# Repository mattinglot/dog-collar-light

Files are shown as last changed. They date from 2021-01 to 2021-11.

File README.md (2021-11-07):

# Dog Collar Light
Developed by Matt Inglot

## Overview
This is the LED dog collar light PCB and firmware that I built for my dog Joey and a few of his friends.

Overview of the Light:
https://youtu.be/FvTPfEKD1Q0

Details about the PCB Design:
https://youtu.be/JEl7wfQJ-MM

## License
* The firmware source code is licensed under the MIT license.
* The PCB design is licensed under the Creative Commons Attribution Share Alike 4.0 International license.

See the LICENSE file in each folder of the project for the applicable license.

## Share Your Creations!
If you end up building one of these lights, I would really love to know! Please leave a comment on https://youtu.be/FvTPfEKD1Q0 with a link to your work.

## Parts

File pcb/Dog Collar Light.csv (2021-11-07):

Ref | Value | Part | Footprint | Description | Vendor
BT1 | 2xCR2032 | Device:Battery | mi-footprint:BatteryHolder_Keystone_3024 | Multiple-cell battery
C3 | 22uF | Device:C | Capacitor_SMD:C_0805_2012Metric_Pad1.15x1.40mm_HandSolder | Unpolarized capacitor
C4 | 22uF | Device:C | Capacitor_SMD:C_0805_2012Metric_Pad1.15x1.40mm_HandSolder | Unpolarized capacitor
C5 | 22uF | Device:C | Capacitor_SMD:C_0805_2012Metric_Pad1.15x1.40mm_HandSolder | Unpolarized capacitor
C6 | 22uF | Device:C | Capacitor_SMD:C_0805_2012Metric_Pad1.15x1.40mm_HandSolder | Unpolarized capacitor
C7 | 0.1uF | Device:C | Capacitor_SMD:C_0805_2012Metric_Pad1.15x1.40mm_HandSolder | Unpolarized capacitor
D1 | LED_RGB | Device:LED_RGB | mi-footprint:LED_Cree-SLV6A | RGB LED, 6 pin package
D2 | LED_RGB | Device:LED_RGB | mi-footprint:LED_Cree-SLV6A | RGB LED, 6 pin package
J1 | AVR-ISP-6 | Connector:AVR-ISP-6 | Connector_PinHeader_2.54mm:PinHeader_2x03_P2.54mm_Vertical | Atmel 6-pin ISP connector
Q1 | MBT3904DW1T1G | dk_Transistors-Bipolar-BJT-Arrays:MBT3904DW1T1G | digikey-footprints:SOT-363 | TRANS 2NPN 40V 0.2A SC88
R1 | 100 | Device:R | Resistor_SMD:R_0805_2012Metric_Pad1.15x1.40mm_HandSolder | Resistor
R2 | 68 | Device:R | Resistor_SMD:R_0805_2012Metric_Pad1.15x1.40mm_HandSolder | Resistor
R3 | 68 | Device:R | Resistor_SMD:R_0805_2012Metric_Pad1.15x1.40mm_HandSolder | Resistor
R4 | 100 | Device:R | Resistor_SMD:R_0805_2012Metric_Pad1.15x1.40mm_HandSolder | Resistor
R5 | 68 | Device:R | Resistor_SMD:R_0805_2012Metric_Pad1.15x1.40mm_HandSolder | Resistor
R6 | 68 | Device:R | Resistor_SMD:R_0805_2012Metric_Pad1.15x1.40mm_HandSolder | Resistor
R7 | 330 | Device:R | Resistor_SMD:R_0805_2012Metric_Pad1.15x1.40mm_HandSolder | Resistor
R8 | 10k | Device:R | Resistor_SMD:R_0805_2012Metric_Pad1.15x1.40mm_HandSolder | Resistor
R9 | 10K | Device:R | Resistor_SMD:R_0805_2012Metric_Pad1.15x1.40mm_HandSolder | Resistor
R10 | 330 | Device:R | Resistor_SMD:R_0805_2012Metric_Pad1.15x1.40mm_HandSolder | Resistor
R11 | 330 | Device:R | Resistor_SMD:R_0805_2012Metric_Pad1.15x1.40mm_HandSolder | Resistor
R12 | 6.8k | Device:R | Resistor_SMD:R_0805_2012Metric_Pad1.15x1.40mm_HandSolder | Resistor
R13 | 6.8k | Device:R | Resistor_SMD:R_0805_2012Metric_Pad1.15x1.40mm_HandSolder | Resistor
S1 | 222PJVAAR | dk_Tactile-Switches:1825910-6 | mi-footprint:Switch_222PJVAAR | SWITCH TACTILE SPST-NO 0.05A 24V
U2 | ATtiny84A-SSU | MCU_Microchip_ATtiny:ATtiny84A-SSU | Package_SO:SOIC-14_3.9x8.7mm_P1.27mm | 20MHz, 8kB Flash, 512B SRAM, 512B EEPROM, debugWIRE, SOIC-14

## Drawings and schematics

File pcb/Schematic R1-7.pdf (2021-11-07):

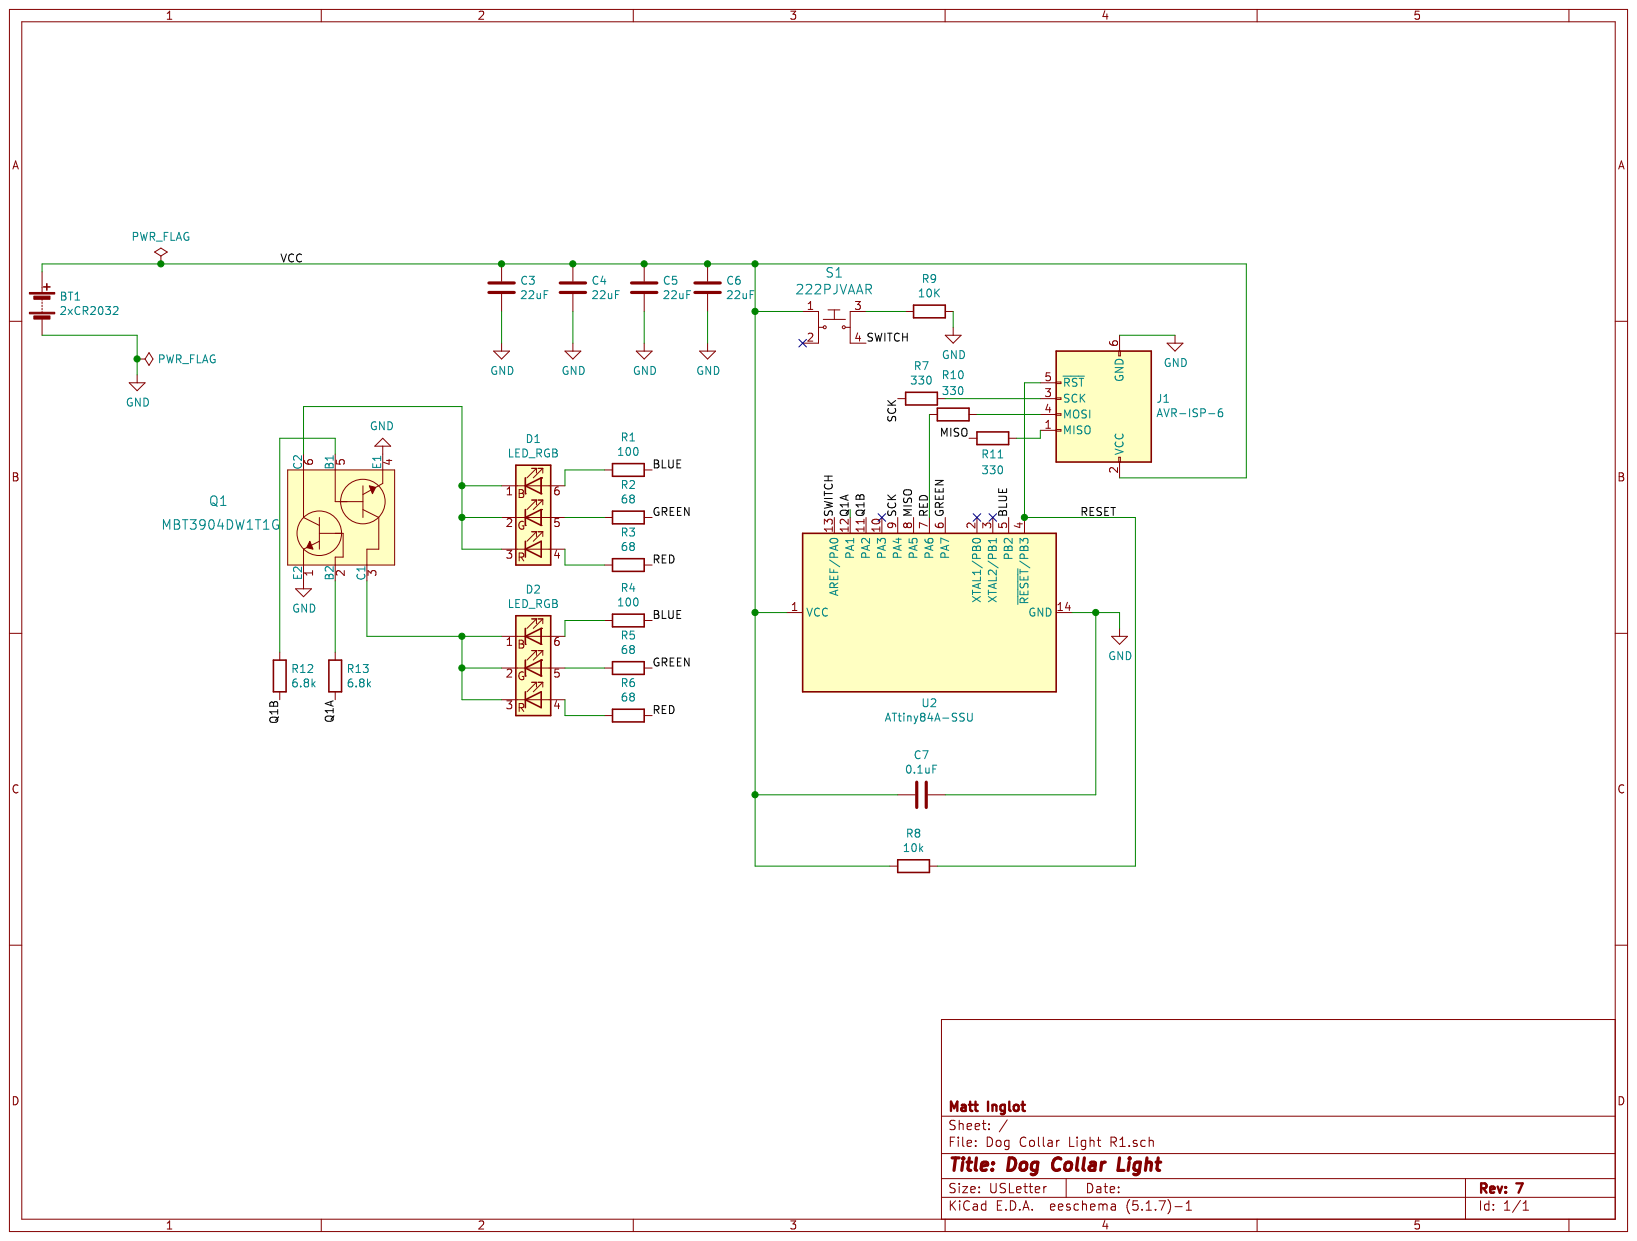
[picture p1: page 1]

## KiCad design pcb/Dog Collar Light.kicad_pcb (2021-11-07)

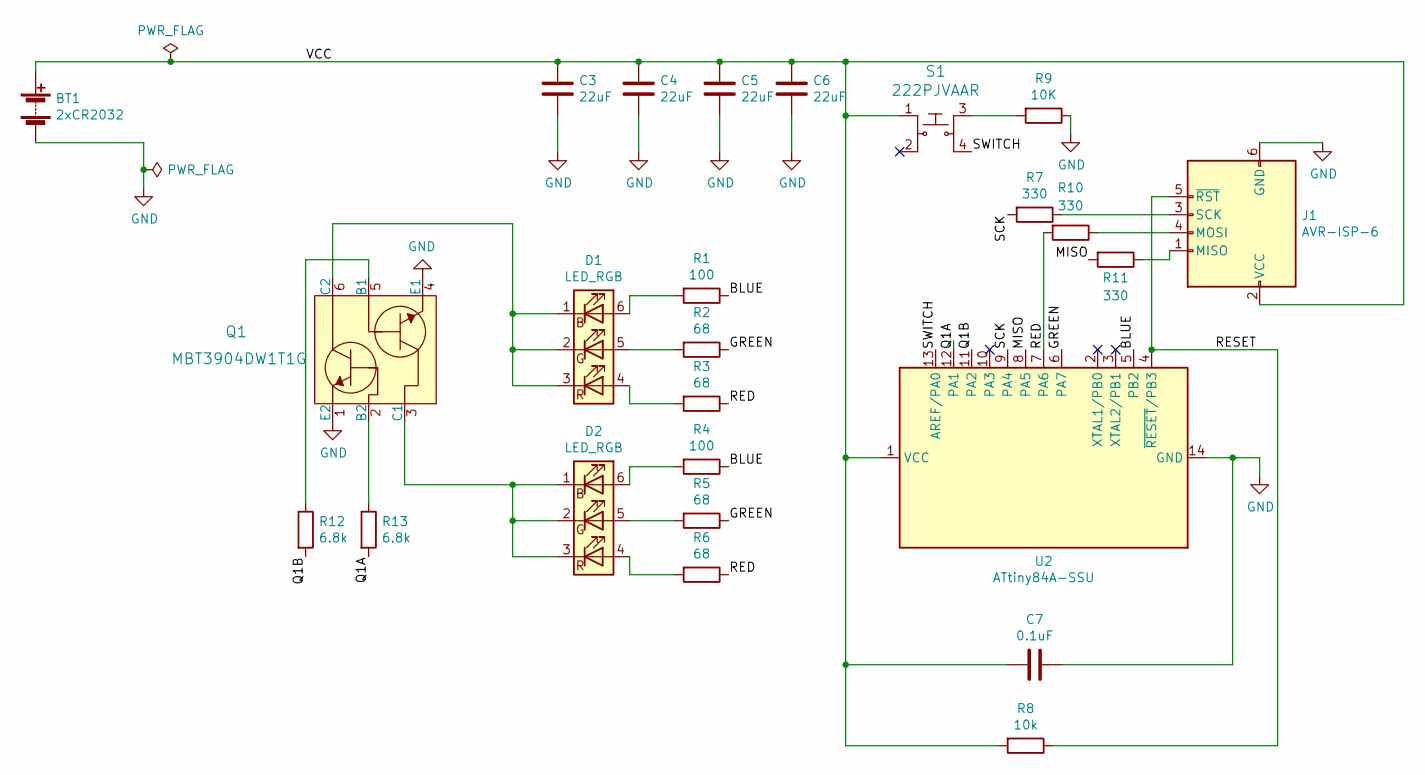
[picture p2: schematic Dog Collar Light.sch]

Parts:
BT1: 2xCR2032; BatteryHolder_Keystone_3024
C3, C4, C5, C6: 22uF; C_0805_2012Metric_Pad1.15x1.40mm_HandSolder
C7: 0.1uF; C_0805_2012Metric_Pad1.15x1.40mm_HandSolder
D1, D2: LED_RGB; LED_Cree-SLV6A
J1: AVR-ISP-6; PinHeader_2x03_P2.54mm_Vertical
Q1: MBT3904DW1T1G; SOT-363; MPN MBT3904DW1T1G; Digi-Key_PN MBT3904DW1T1GOSCT-ND
R1, R4: 100; R_0805_2012Metric_Pad1.15x1.40mm_HandSolder
R2, R3, R5, R6: 68; R_0805_2012Metric_Pad1.15x1.40mm_HandSolder
R7, R10, R11: 330; R_0805_2012Metric_Pad1.15x1.40mm_HandSolder
R8: 10k; R_0805_2012Metric_Pad1.15x1.40mm_HandSolder
R9: 10K; R_0805_2012Metric_Pad1.15x1.40mm_HandSolder
R12, R13: 6.8k; R_0805_2012Metric_Pad1.15x1.40mm_HandSolder
S1: 222PJVAAR; Switch_222PJVAAR; MPN 1825910-6; Digi-Key_PN 450-1650-ND
U2: ATtiny84A-SSU; SOIC-14_3.9x8.7mm_P1.27mm

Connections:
/BLUE: R1.1, R4.1, U2.5 (PB2)
/GREEN: R2.1, R5.1, U2.6 (PA7)
/MISO: R11.2, U2.8 (PA5)
/Q1A: R13.2, U2.12 (PA1)
/Q1B: R12.2, U2.11 (PA2)
/RED: R3.1, R6.1, R10.2, U2.7 (PA6)
/SCK: R7.2, U2.9 (PA4)
/SWITCH: S1.4, U2.13 (AREF/PA0)
/VCC: BT1.1 (+), C3.1, C4.1, C5.1, C6.1, C7.2, J1.2 (VCC), R8.2, S1.1, U2.1 (VCC)
GND: BT1.2 (-), C3.2, C4.2, C5.2, C6.2, C7.1, J1.6 (GND), Q1.1 (E2), Q1.4 (E1), R9.1, U2.14 (GND)
unnamed: D1.1 (RK), D1.2 (GK), D1.3 (BK), Q1.6 (C2)
unnamed: D1.4 (BA), R3.2
unnamed: D1.5 (GA), R2.2
unnamed: D1.6 (RA), R1.2
unnamed: D2.1 (RK), D2.2 (GK), D2.3 (BK), Q1.3 (C1)
unnamed: D2.4 (BA), R6.2
unnamed: D2.5 (GA), R5.2
unnamed: D2.6 (RA), R4.2
unnamed: J1.1 (MISO), R11.1
unnamed: J1.3 (SCK), R7.1
unnamed: J1.4 (MOSI), R10.1
unnamed: J1.5 (~RST), R8.1, U2.4 (~RESET~/PB3)
unnamed: Q1.2 (B2), R13.1
unnamed: Q1.5 (B1), R12.1
unnamed: R9.2, S1.3

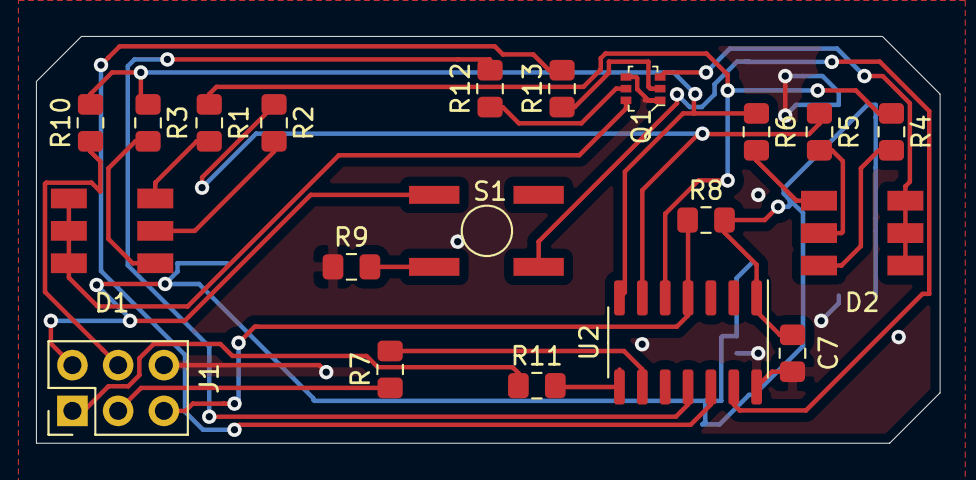
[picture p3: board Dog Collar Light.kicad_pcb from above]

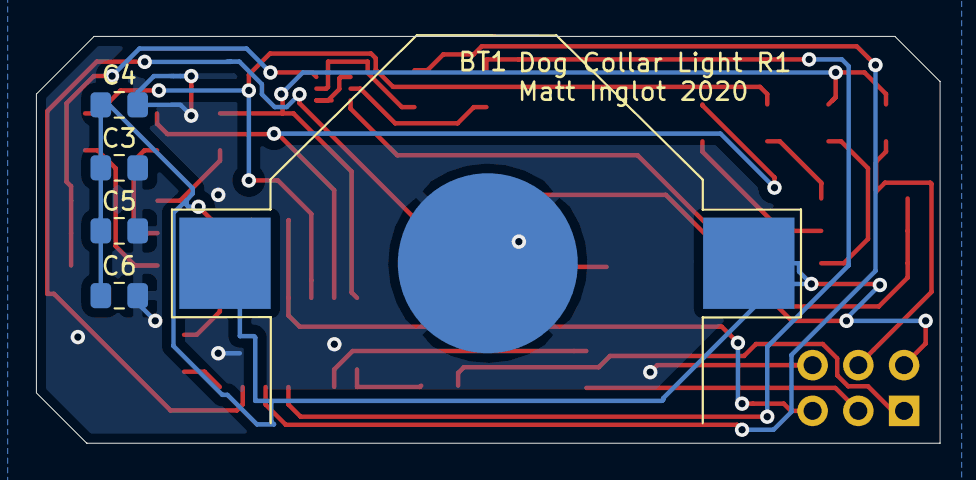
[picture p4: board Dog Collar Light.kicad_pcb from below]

Board: 2 copper layers, 50.2 x 22.6 mm, 25 parts (5 on the bottom side), 25 nets.

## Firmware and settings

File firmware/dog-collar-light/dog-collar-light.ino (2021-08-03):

#include <avr/interrupt.h>
#include <avr/sleep.h>
#include <avr/power.h>
#include <avr/wdt.h> //Needed to enable/disable watch dog timer
#include <EEPROM.h>

#include "config.h"
#include "colorlib.h"
#include "modes.h"

// where various data is stored in EEPROM
#define EEPROM_ADDR_ACTIVE_MODE 0x02 // last active mode

typedef struct ColorShift {
  unsigned int cycleTime; // how long should this shift take
  unsigned char colors[3];
};


int verifyLightLevel = 10; // the light level to set verify route to in the beginning
volatile int interruptBrightness = 10;

volatile unsigned long modeStartTime = 0; // the millis() time that this mode started at
volatile byte activeMode = 0; // the currently active light show mode.
volatile bool isSleeping = false; // whether we are currently in sleep mode

volatile bool inWatchdog = false; // set to true when entering watchdog, set to false when exiting

// turning the light off requires a number of button presses to occur in a short
// interval. We handle this by checking if the button has been pressed (actually if
// mode has been changed) in rapid succession.
unsigned long offButtonPressStart = 0;
unsigned int offButtonPressCount = 0;

// track whether we are in cooldown mode on start to ensure button presses are ignored
unsigned long coolDownStart = 0;

// when was the light last turned on
unsigned long lastOn = 0;

// Power saving measure to force the light to go to sleep if processor stays on and NOT
// in an "on" state for too long. Such as someone holding down the button when the product
// is off.
volatile bool forcedSleep = false;

// used to indicate that the current state should be saved to eeprom
// this is used a part of system to delay saving the active mode to eeprom
// by 1s to avoid rapid switching between modes causing wasteful eeprom writes
volatile bool eepromSaveRequired = false;

int currentColors[3] = {0,0,0}; 
int ledStates[2] = {0,0};

void setup() {
  
  // put your setup code here, to run once:
  pinMode(LED_RED, OUTPUT);
  pinMode(LED_GREEN, OUTPUT);
  pinMode(LED_BLUE, OUTPUT);
  pinMode(LED_SWITCH_1, OUTPUT);
  pinMode(LED_SWITCH_2, OUTPUT);
  pinMode(BUTTON_MODE, INPUT);

  // CONFIGURE TIMERS FOR PWM
  
  /*
   * WGM10, WGM12: Fast PWM, 8-bit TOP=255
   * CS10: No prescaler
   * COM1A1: Pin 6 to LOW on match with OCR1A and to HIGH on TOP
   */
  //TCCR1A = _BV(COM1A1) | _BV(WGM10);
  //TCCR1B = _BV(CS10) | _BV(WGM12);
  /*
   * 50% duty cycle
   * 4 kHz with 1MHz CPU clock
   */
  //OCR1A = 127;

  // CONFIGURE INTERRUPTS
  // turn on interrupts.
  //PCMSK0 |= 0b00000100;     // PCINT2  (PA2/pin 11)

  MCUCR &= ~(_BV(ISC01) | _BV(ISC00));      //INT0 on any change
  //MCUCR &= (_BV(ISC01) | _BV(ISC00)); // trigger on rising edge
  
  
  
  //MCUCR |= _BV(ISC00); // set INT0 to trigger on rising edge
  PCMSK0 |= 0b00000001;     // PCINT0  (PA0/pin 13)
  //GIFR   = 0b00000000;     // clear any outstanding interrupts
  GIMSK  |= 0b00010000;     // enable external interrupt
  //GIMSK |= _BV(INT0);
  //GIMSK |= _BV(PCINT0);
  sei();                 // enables interrupts


  startMode(getLastSavedMode());
  //startMode(MODE_UTILITY_OFF);
  //startMode(MODE_UTILITY_TEST);
}

void loop() {

  // verifies the function of the leds
  //verifyLeds();
  //verifyLedsFull(); 

   // run the active mode
   runActiveMode();

   // don't process button presses if we are cooling down from start up
   if( coolDownStart != 0 ) {
    if( millis() - coolDownStart > START_COOLDOWN_MILLIS)
      coolDownStart = 0;
   }
   else {
    // check the state of the button to see if anything needs to be done
    checkButtonState();
   }

   if( (millis() - lastOn) > AUTO_OFF_MILLIS ) { 
    startMode(MODE_UTILITY_OFF);
   }
}


/**
 * Returns the last mode that was on (saved via EEPROM)
 * or MODE_UTILITY_OFF if no valid mode found.
 */

byte getLastSavedMode() {
  byte mode;
  EEPROM.get(EEPROM_ADDR_ACTIVE_MODE, mode);
  return mode;
}


/**
 * Saves the current state of the light to eeprom. Used so that if 
 * dog manages to momentary cause light to lose power due to loose
 * battery connection, light will resume previous mode rather than
 * turn off.
 */

void saveStateToEeprom() {
  // if we are off or in a regular (not utility) mode then save the current mode
  // don't save utility modes as we don't want to start up in utility mode and just
  // wastes eeprom (which has limited writes)
  if( activeMode <= LAST_MODE )
    EEPROM.update(EEPROM_ADDR_ACTIVE_MODE, activeMode);
}


/**
 * Turns on a given light mode and resets it to start from scratch
 */

void startMode( int mode ) {

  // if turning off then immediately save that state to eeprom
  // else flag it for saving
  if( mode == MODE_UTILITY_OFF )
    saveStateToEeprom();
  else if( mode != activeMode)
    eepromSaveRequired = true;
    
  activeMode = mode;
  modeStartTime = millis();
}


unsigned long funGradient( unsigned long cycleTime, unsigned long effectStart, unsigned long duration ) {
  bool led1On = false;
  bool led2On = false;

  int effectTime = cycleTime - effectStart;
  int red;
  int green;
  int blue;
  int redSteps;
  int greenSteps;
  int blueSteps;

  ColorShift colorstest[3] = {
    { 2500, 0, 10, 100 },
    { 2500, 0, 10, 100 },
  };

  unsigned char colors[3][3] = {
    {0,10,100},{100,10,0},{50,0,50}
    };

  if( cycleTime > effectStart && cycleTime < (effectStart + duration) ) {

    int colorIndex = (int) (floor(effectTime / (duration / 3)));

    if( colorIndex < 0 )
      colorIndex = 0;

    if( colorIndex > 2 )
      colorIndex = 2;
    
    // want Red to go from Min to Max over duration
    if( colors[colorIndex][RED] > 0 ) {
      redSteps = duration / colors[colorIndex][0];
      red = effectTime / redSteps + MIN_BRIGHTNESS;
    }
    else
      red = 0;

    if( colors[colorIndex][GREEN] > 0 ) {
      greenSteps = duration / colors[colorIndex][1];
      green = effectTime / greenSteps + MIN_BRIGHTNESS;
    }
    else
      green = 0;

    if( colors[colorIndex][BLUE] > 0 ) {
      blueSteps = duration / colors[colorIndex][2];
      blue = effectTime / blueSteps + MIN_BRIGHTNESS;
    }
    else
      blue = 0;

    if( (effectTime / 1000) % 2 ) {
      led1On = true;
      led2On = false;
    } else {
      led1On = false;
      led2On = true;
    }

    setLedState( led1On, led2On );
    setColor( red, green, blue, false );
  }

  return effectStart + duration;
}


void turnOff() {
  ADCSRA &= ~_BV(ADEN);      // ADC off
  
  set_sleep_mode(SLEEP_MODE_PWR_DOWN);

  // enable sleep mode
  sleep_enable(); 
  sei();              

  isSleeping = true;

  // sleep cpu until an interrupt occurs
  sleep_cpu();    

  // wakeup from sleep tasks.
  sleepWake();
}


/**
 * Wakeup from sleep.
 */

void sleepWake() {

  cli();    
  sleep_disable();                        // Clear SE bit
  ADCSRA |= _BV(ADEN);                    // ADC on
  sei();
  lastOn = millis();
  isSleeping = false;
}

void sleepIdle( int length ) {

  if (length > 9) 
    length = 9; //Limit incoming amount to legal settings

  byte bb = length & 7;
  
  if (length > 7) 
    bb |= (1 << 5); //Set the special 5th bit if necessary

  //This order of commands is important and cannot be combined
  MCUSR &= ~(1 << WDRF); //Clear the watch dog reset
  WDTCSR |= (1 << WDCE) | (1 << WDE); //Set WD_change enable, set WD enable
  WDTCSR = bb; //Set new watchdog timeout value
  WDTCSR |= _BV(WDIE); //Set the interrupt enable, this will keep unit from resetting after each int
  inWatchdog = true;

  isSleeping = true;
  // use ide sleep mode which still allows PWM to function
  set_sleep_mode(SLEEP_MODE_IDLE);

  // attiny frequently exits idle mode to update its own timer
  // so keep going back to sleep until inWatchdog has been set to false by
  // watchdog interrupt
  while( inWatchdog ) {
    set_sleep_mode(SLEEP_MODE_IDLE);
    sleep_mode();
  }
    
  isSleeping = false;
  ADCSRA |= _BV(ADEN);
}


void runActiveMode() {
  // convert mode time to how much time has elapsed in the current cycle
  unsigned long cycleTime = millis() - modeStartTime;
  bool restartMode = false;

  switch( activeMode )
  {
    case 0:
      restartMode = runMode0(cycleTime);
      break;
    
    case 1:
      restartMode = runMode1(cycleTime);
      break;

    case 2:
      restartMode = runMode2(cycleTime);
      break;

    case 3:
      restartMode = runMode3(cycleTime);
      break;

    case MODE_UTILITY_WAKE:
      restartMode = runModeUtilityWake(cycleTime);
      break;

    case MODE_UTILITY_TEST:
      restartMode = runModeUtilityTest(cycleTime);
      break;      

    /// if in unrecognized mode then switch off
    default:
      startMode(MODE_UTILITY_OFF);
      restartMode = true;
  }

  // To preserve eeprom write cycles, the current mode is only saved if it has been
  // active for at least a second or one full mode cycle, whichever comes first.
  if( eepromSaveRequired && (restartMode || cycleTime > 1000) ) {
    saveStateToEeprom();
    eepromSaveRequired = false;
  }

  if( restartMode )
    startMode(activeMode);
}


/**
 * Figures out what mode should be next based on current mode. Only
 * runs through active modes
 */

void startNextMode()
{
  activeMode++;

  if( activeMode > MODE_COUNT )
    activeMode = 1; // gone through all modes so turn off
  
  startMode(activeMode);
}


/**
 * Interrupt handler for watchdog interrupt. 
 * Don't remove or mcu will reset after watchdog ends.
 */

ISR(WDT_vect) {
  inWatchdog = false;
}

/**
 * Interrupt handler for mode button which gets called everytime the 
 * button state changes.
 */

ISR(PCINT0_vect) {

   
  // if we are here, then state of the button has changed so call checkButtonState
  // this interrupt handler is mostly needed for when the light is in sleep mode.
  // Otherwise the checkButtonState gets called during every cycle of the main 
  // loop and we don't continue to call it here (to avoid the interrupt handler calling
  // checkButtonState() while we are already in checkButtonState).
  if( isSleeping )
    checkButtonState(); 
}


/**
 * Returns true if sleep has been forced. Will keep returning true until endForcedSleep
 * is called
 */

bool isForcedSleep()
{
  if( forcedSleep )
  {
    return true;
  }

  return false;
}


/**
 * Starts a mandatory forced sleep to ensure that device goes to 
 * sleep on the next button check no matter what is going on, and if
 * button is pressed down then that press is ignored.
 */

void startForcedSleep()
{
  forcedSleep = true;
}


/**
 * Ends forced sleep mode.
 */

void endForcedSleep()
{
  forcedSleep = false;
}


/**
 * Monitors the state of the on/off button and acts accordingly.
 * To work properly, this function is called everytime the processor
 * loops as well as by the hardware interrupt handler when button state 
 * changes.
 */

void checkButtonState()
{
static unsigned long lastInterruptTime = 0;
  static bool doneInterrupt = false;
  static bool ignoreButtonHigh = false; // if set to true, ignore button high because it's being checked by wakeup
  unsigned long interruptTime = millis();
  static bool inButtonPress = false; // this gets set to true when button position is high
  static unsigned long lastButtonPressStart = 0; // last time button state changed to high
  unsigned long buttonPressDuration = 0; // how long button has been pressed
 
  if( isForcedSleep() )
  {
    if( !ignoreButtonHigh && digitalRead(BUTTON_MODE) == HIGH )
      ignoreButtonHigh = true;

    endForcedSleep();
    startMode(MODE_UTILITY_OFF);
    return;
  }

  // if in the check for wakeup mode then don't do any further processing here
  if( activeMode == MODE_UTILITY_WAKE )
    return;

  // if we are in sleep mode then we can't debounce button in the interrupt since
  // attiny won't increment millis. Instead we wake up and start a special mode that 
  // waits for the power button to be pressed long enough and starts regular mode, or 
  // goes back to sleep. 
  if( !ignoreButtonHigh && isSleeping && (digitalRead(BUTTON_MODE) == HIGH) ) {
    //startNextMode();

    // set this flag to high so we know that the button press is as a result of 
    // waiting for light to turn on. This keeps us from accidentally moving modes
    // if user holds button down too long
    //ignoreButtonHigh = true;
    startMode(MODE_UTILITY_WAKE);
    return;
  }

  // if button goes low we can reset the ignoreButtonHigh flag
  // this also means the interrupt can end here because we've woken up
  // and mode 1 was started by MODE_UTILITY_WAKE
  if( ignoreButtonHigh && digitalRead(BUTTON_MODE) == LOW ) {
    ignoreButtonHigh = false;
    return;
  }

  // if we got to this point and we're ignoring button high then 
  // just return from the handler so that the button press is not
  // processed further
  if( ignoreButtonHigh )
    return;

  // if in sleep mode then don't process further button logic
  if( isSleeping )
    return;

  // NORMAL (NOT ASLEEP) INTERRUPT HANDLER STARTS HERE
  
  // if inside a button press, see how long button has been held down for
  if( inButtonPress )
    buttonPressDuration = millis() - lastButtonPressStart;

  bool doneProcessing = false;

  // check if we've been in button press long enough to turn off light
  // this check happens on button pressed down
  if( !doneProcessing & inButtonPress && digitalRead(BUTTON_MODE) == HIGH ) {

    // check if button was held past threshold to turn off
    if( buttonPressDuration > MILLIS_TO_OFF ) {
      // don't want user continuing to hold button down to turn light
      // back on so ignore high state until button goes low again
      ignoreButtonHigh = true;  
      doneProcessing = true;
      startMode(MODE_UTILITY_OFF);
    }
  }

  // changing modes happens on button release to not conflict with 
  // turn off intent.
  if( !doneProcessing && inButtonPress && digitalRead(BUTTON_MODE) == LOW ) {

    // check if button was held past the debounce minimum
    if( buttonPressDuration > DEBOUNCE_MILLIS ) {

      startNextMode();

      #ifdef RAPID_PRESS_OFF
        
        // check if we are turning off the light
        if( (millis() - offButtonPressStart) < MILLIS_TO_OFF ) {
          // we are still within the MILLIS_TO_OFF range so increment the off button press count
          offButtonPressCount++;
        }
        else {
          // reset off button counter
          offButtonPressCount = 1;
          offButtonPressStart = millis();
        }
  
        if( offButtonPressCount >= PRESSES_TO_OFF ) {
          offButtonPressCount = 0;
          offButtonPressStart = millis();
          startMode(MODE_UTILITY_OFF);
        }
      #endif
      
      doneProcessing = true;
    }
  }

  // adjust state variables to track whether we are in a button press or not
  if( !ignoreButtonHigh && digitalRead(BUTTON_MODE) == HIGH ) {
    if( inButtonPress == false )
      lastButtonPressStart = millis();
      
    inButtonPress = true;
  }
  else
    inButtonPress = false;  
}


/**
 * Verification routine for verifying full brightness of LEDs
 * Used in development to calibrate LED resistor values against
 * real world performance of coin cell batteries.
 */

void verifyLedsFull() {

  int lightLevel = MAX_BRIGHTNESS;
  static int color = RED;

  switch( color ) {
    case RED:
     setLedState(true,false);
     setColor( lightLevel, 0, 0, false );
     break;

    case GREEN:
     setLedState(true,false);
     setColor( 0, lightLevel, 0, false );
     break;
     
    case BLUE:
     setLedState(true,false);
     setColor( 0, 0, lightLevel, false );
     break;
    
  }

  // change which color is active on button press
  if( digitalRead(BUTTON_MODE) == HIGH ) {
    color++;

    if( color > BLUE )
      color = RED;
  }
}


/**
 * Verifies the function of the LEDs by turning each one on
 * individually and holding that value for 5 seconds.
 */

void verifyLeds() {

  int lightLevel = 10;


  setLedState(true,true);
  setColor( lightLevel, 0, 0, false );
  delay(5000);
  setColor( 0, lightLevel, 0, false );
  delay(5000);
  setColor( 0, 0, lightLevel, false );
  delay(5000);

  setLedState(true,false);
  setColor( lightLevel, 0, 0 );
  delay(3000);
  setColor( 0, lightLevel, 0 );
  delay(3000);
  setColor( 0, 0, lightLevel );
  delay(3000);

  setLedState(false,true);
  setColor( lightLevel, 0, 0 );
  delay(3000);
  setColor( 0, lightLevel, 0 );
  delay(3000);
  setColor( 0, 0, lightLevel );
  delay(3000);

  setLedState(true,true);
  setColor( lightLevel, lightLevel, 0, false );
  delay(3000);
  setColor( 0, lightLevel, lightLevel, false );
  delay(3000);
  setColor( lightLevel, 0, lightLevel, false );
  delay(3000);
  setColor( lightLevel, lightLevel, lightLevel, false );
  delay(3000);
}

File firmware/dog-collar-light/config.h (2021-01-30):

#ifndef _CONFIG_H 
#define _CONFIG_H 

#define LED_RED 6
#define LED_GREEN 7
#define LED_BLUE 8
#define LED_SWITCH_1 2 //0
#define LED_SWITCH_2 1
#define BUTTON_MODE 0 // PA0/PCINT0

// lowest "on" value for LED. Do NOT use to turn color off
#define MIN_BRIGHTNESS 2

// highest "on" value for LED, aka the brightest setting we allow on LED
#define MAX_BRIGHTNESS 255

// maximum "output" across all LEDs. If multiple LEDs are on such that this 
// output is exceeded then the LEDs are throttled
#define MAX_LED_OUTPUT 440

// number of distinct brightness levels available to us
#define STEPS (MAX_BRIGHTNESS - MIN_BRIGHTNESS)

#define RED 0
#define GREEN 1
#define BLUE 2

#define MILLIS_TO_START 1500 // how many milliseconds user has to press button PRESSES_TO_START times to turn on
#define PRESSES_TO_START 3 // how many times button has to be rapidly pressed on/off to start

#define START_COOLDOWN_MILLIS 500 // milliseconds button presses are ignored entirely after start to avoid accidentally switching modes

// uncomment to enable the ability to press button rapidly to turn off similar to
// how the start function works
//#define RAPID_PRESS_OFF
#define MILLIS_TO_OFF 1000   // how many milliseconds on button must be pressed to turn off light
#define PRESSES_TO_OFF 4 // how many times button has to be rapidly pressed on/off to turn off

#define DEBOUNCE_MILLIS 50 // how many milliseconds a button must be debounced for
#define DEBOUNCE_MILLIS_LONG_PRESS 500 // how many milliseconds is considered a long press

#define AUTO_OFF_MILLIS (60*60*1.5*1000) // turn off automatically after 1.5 hours

#define USE_SLEEP_MODE true // if false does not use sleep when powering done, for debug only!

#endif // _CONFIG_H

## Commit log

2021-01-30 Added eeprom save so momentary loss of power doesn't cause light to turn off (eg dog shaking head causing battery to briefly lose contact)
    Also renamed main file to dog-collar-light.ino to match repo name.
    [dog-collar-light.ino]
2021-11-07 Added Kicad files.
    [Dog Collar Light R1-B_Cu.gbr, Dog Collar Light R1-B_Mask.gbr, Dog Collar Light R1-B_SilkS.gbr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]
2021-11-12 Updated recommended switch to one that fits case better. It is much shorter so you can squish the case more to turn on/off.
    [Dog Collar Light.sch]
2021-11-12 Removed kicad .bak files.

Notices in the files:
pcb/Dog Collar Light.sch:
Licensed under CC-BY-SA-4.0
